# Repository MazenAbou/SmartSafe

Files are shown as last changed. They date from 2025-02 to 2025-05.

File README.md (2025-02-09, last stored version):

# Smart Safe
The Smart Safe is a secure storage system that can be unlocked using a keypad passcode or fingerprint authentication. This prototype, built using Arduino, allows for quick development and testing.

Hardware Components
Microcontroller: Arduino Uno
Input Modules: 4x4 Keypad, Fingerprint Sensor
Output Modules: LCD Display, Buzzer, LED
Lock Mechanism: Servo Motor
Power Supply: 5V Adapter

How It Works
The user enters a passcode on the keypad OR scans a fingerprint for authentication.
If verified, the safe unlocks (servo motor activates).
If authentication fails, the system gives a warning (buzzer & LED).

Next Step:
Transition from Arduino board to a standalone ATmega328P microcontroller.

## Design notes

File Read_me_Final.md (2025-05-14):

Smart Safe Project
Overview:
The smart safe is for anyone with important documents or stuff who wants to keep them away from their roommate, siblings, parents, kids, or even their wives. It’s portable and can fit in a drawer or under the bed. It has security features that trigger an alarm if someone tampers with it. It can be opened using the tag reader or by entering a code using a keypad. Also, an LCD provides a user interface for menu navigation. Options include changing the password, managing RFID tags, and setting the unlock tone.
Key Features and Components:
Microcontroller Chip (ATMega328P): The brain of this project. It has the program code stored in it. It receives/sends signals between other components through the PCB board.
Power Supply: A 3.7V lithium-ion polymer (LiPo) battery combined with a boost module, which steps the voltage up to 5V, which is sufficient to power the microcontroller and peripherals.
Servo Motor: Connected to the lock tongue. Mechanically controls the locking mechanism. It rotates 90 degrees upon receiving signals from the microcontroller to lock or unlock the safe.
Door Sensor: It detects the status of the safe’s door. If the safe is locked and the door is moving, it will send a signal to the microcontroller, and the alarm will be triggered. Also, when the safe door closes, the lock automatically activates, and it prevents the lock from being activated if the door is open.
Card reader (RFID) module: This will give the user the option to open the lock using an authorized RFID card instead of entering a password.
16x2 LCD Display: It will display the lock status and the menu, which will allow the user to choose the option to change the password, or add/remove a tag, and set a tone when the lock opens.
4 x 4 Keypad: This will allow the user to navigate through the menu and enter the password.
Operation Instructions:
First, connect the Smart Safe to a power source using USB-C.
Once powered, the LCD will initialize and prompt the user to enter the default password. Using the keypad, enter the numbers “1234”.
Upon successful entry, a tone will play, and a message will indicate that the safe is unlocked. You will have five seconds to open the safe’s door before it relocks automatically. Open the safe’s door by pulling the handle upward carefully. The door can rotate up to 90 degrees.
 After opening the door, press the “D” key to access the main menu. Navigate through the menu with the buttons “A” to go up, “B” to go down, “C” to select, and “D” to go back.
To change the password, go up to the first option on the menu, then hit “C”. You will be prompted to enter the old password, enter “1234”, then you will be prompted to enter the new password. Enter a four-digit password of your choice, A confirmation message will appear upon success, “Password Changed”.
To add/remove tags, go to the second option on the menu “Add/Remove tags” and hit “C”. You will see two options: “Add tags” and “Remove tags”. Select the first option to add a new tag and hit “C”. You will be prompted to tap the new tag. Grab the tag you want to add and tap it on the safe around one inch below the LCD. A message will appear, “Tag is added.” Hit “D” to go back to the “Add/Remove tags” menu. You can check all registered tags and remove them by selecting the second option, “Remove tags” and hit “C”. A list of all registered tags will be displayed. Navigate to the one you would like to remove and hit the key “C”. You will be prompted to hit the key “C” again if you are sure or you can hit “D” to cancel and go back to the list.
The third option on the main menu is to change the tone that will be played when the lock opens. Select the third option, “Opening tones” then hit “C”. A list of tones will appear, each tone has a name that describes the tone. You can select the tone you like by pushing the key “C”, or you can turn it off by going all the way up to the first option “off” and hitting the button “C”. 
Future Improvements
Possible upgrades include opening the safe via fingerprint. Wi-Fi connectivity for remote monitoring, and a mobile app for access control and notifications.

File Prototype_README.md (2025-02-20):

# Smart Safe
The Smart Safe is a secure storage system that can be unlocked using a keypad passcode. This prototype, built using Arduino, allows for quick development and testing.

Hardware Components
Microcontroller: Arduino Uno
Input Modules: 4x4 Keypad.
Output Modules: LCD Display, Buzzer, LEDs
Lock Mechanism: Servo Motor
Power Supply: 5V / 12V Adapter

How It Works
The user enters a passcode on the keypad.
If verified, the safe unlocks (servo motor activates).
If authentication fails, the system gives a warning (buzzer & LED).

Next Step:
Transition from Arduino board to a standalone ATmega328P microcontroller, adding a card reader, and approach sensor (or similar).

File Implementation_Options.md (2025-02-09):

The Smart Safe system can be implemented using different architectures based on the level of security, complexity, and scalability required. 

Option 1: Microcontroller-Based (Arduino).
Pros:
Simple and cost-effective.
Low power consumption.
Ideal for standalone operation.
Cons:
Limited storage for logging access.
No built-in remote access without additional modules.
Architecture:
Microcontroller 
  -  Arduino as the central processing unit.
  -  Keypad & Fingerprint Sensor as input.
  -  Solenoid Lock/Servo Motor.
  -  LCD Display for feedback.
  -  EEPROM/Flash Memory to store credentials.

Option 2: Raspberry Pi-Based.
Pros:
- More processing power and storage.
- Allows for network-based control (Wi-Fi, Bluetooth, Cloud integration).
Cons:
- Higher power consumption.
- More complex software development.
Architecture:
- Raspberry Pi as the processing unit.
- Touchscreen UI (Optional) instead of a keypad.
- Cloud-based authentication (Optional).

Option 3: Standalone ATmega328P (Without Arduino Board).
  Pros:
- Smaller and cheaper than a full Arduino board.
- More customizable and power-efficient for production use.
- Works well for battery-powered applications.
  Cons:
- Requires external components (crystal oscillator, capacitors, voltage regulator).
- Harder to debug compared to an Arduino board.
  Architecture:
- ATmega328P microcontroller (flashed with Arduino bootloader).
- External 16MHz crystal oscillator with capacitors.
- Manual wiring for inputs (keypad, fingerprint sensor, lock mechanism).
- EEPROM or Flash memory for storing credentials.
- Power regulation circuit (if using external battery).

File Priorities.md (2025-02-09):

High Priority:
1 - Basic Authentication System
    a) Keypad input for passcode entry.
    b) Fingerprint sensor for biometric authentication.
2 - Lock Mechanism
    a) Connect and control solenoid lock/servo motor.
    b) Ensure the lock securely engages/disengages upon authentication.
3 - Power System
    a) Main power supply (adapter or battery).
    b) Implement low-power mode to optimize energy consumption.
4 - Basic Feedback System
    a) Display status messages (successful unlock, incorrect passcode, etc.).
    b) Use buzzer/LEDs for confirmation and alerts.
    
Medium Priority (Security & Usability Enhancements)
1 - Store passcodes and fingerprint data securely in EEPROM/flash memory.
2 - Maintain logs of unlock attempts (successful and failed).
3 - Implement a backup power source for operation during power failure.

Low Priority
1 - Optional Wi-Fi/Bluetooth connectivity to unlock remotely.
2 - Use vibration or magnetic sensors to detect forced entry attempts.
3 - Allow storing multiple fingerprints and passcodes for different users.

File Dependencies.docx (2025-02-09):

# Smart Safe - Dependencies

## 1. Hardware Dependencies

Component | Dependency | Description
Microcontroller (Arduino) | Power Supply | Requires stable power for operation.
Keypad (4x4 Matrix) | Microcontroller | Needs GPIO pins for input detection.
Fingerprint Sensor (R307, GT-511C3) | Microcontroller, Storage | Requires UART/SPI/I2C communication and memory for storing fingerprints.
Lock Mechanism (Solenoid/Servo Motor) | Microcontroller, Power | Needs control signals and sufficient power to operate.
LCD Display | Microcontroller | Requires I2C/SPI communication for visual feedback.
Buzzer/LED Indicator | Microcontroller | Needs GPIO pins to provide user feedback.
Power Supply (Adapter/Battery) | All Components | Supplies energy for the entire system.
Battery Backup (Optional) | Power Supply | Provides power in case of failure.

## 2. Software Dependencies

Feature | Dependency | Description
Keypad Input Handling | Microcontroller Firmware | Requires a code library to read and process inputs.
Fingerprint Authentication | Microcontroller, Sensor Driver | Needs a driver for the fingerprint module and storage for enrolled prints.
Lock Control | Microcontroller, Motor Driver | Requires control logic to activate/deactivate the lock.
User Interface (Display & Buzzer) | Microcontroller Code | Needs code to display messages and provide feedback.
Power Management | Microcontroller, Power Circuit | Requires logic for handling low power mode and switching to backup.
Data Storage (Passcodes & Fingerprints) | EEPROM/Flash Memory | Needs memory allocation and secure storage handling.

## 3. Functional Dependencies

Feature | Depends On | Description
Unlocking the Safe | Keypad/Fingerprint, Microcontroller, Lock Mechanism | Needs user input and control logic to operate the lock.
Security Alerts (Buzzer, Logs) | Microcontroller, Sensors | Requires a trigger system for failed attempts or tamper detection.
Power Backup Activation | Battery, Power Circuit | Needs a switching mechanism when the main power fails.

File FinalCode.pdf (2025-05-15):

#include <Wire.h>

#include <LiquidCrystal_I2C.h>

#include <Keypad.h>

#include <Servo.h>

#include <MFRC522.h>

#define SS_PIN 10

#define RST_PIN 9

MFRC522 mfrc522(SS_PIN, RST_PIN);

LiquidCrystal_I2C lcd(0x27, 16, 2); // Change 0x27 if needed

Servo safeServo;

// Keypad Setup

const byte ROWS = 4;

const byte COLS = 4;

char keys[ROWS][COLS] = {

{'1', '2', '3', 'A'},

{'4', '5', '6', 'B'},

{'7', '8', '9', 'C'},

{'*', '0', '#', 'D'}

};

byte rowPins[ROWS] = {2, 3, 4, 5};

byte colPins[COLS] = {6, 7, 8, A0};

Keypad keypad = Keypad(makeKeymap(keys), rowPins, colPins, ROWS, COLS);

bool isSafeOpen = false;

bool inMenu = false;

bool inTuneMenu = false;

bool inPasswordChange = false;

bool inRFIDManagement = false;

bool inRFIDRemoval = false;

int menuOption = 0;

const int menuLength = 3;

int menuStart = 0;

int selectedTune = 0; // 0 = Mario Tune, 1 = Fur Elise, 2 = Off

const int buzzerPin = A1;

const int buttonPin = A3; // Button connected to pin A3

String currentPassword = "1234";

String newPassword = "";

const int maxRFIDTags = 10;

byte validRFIDs[maxRFIDTags][4];

int numRFIDTags = 0;

unsigned long lastActivityTime = 0;

const unsigned long inactivityInterval = 10000; // 10 seconds

unsigned long unlockTime = 0; // Time when the safe was unlocked

int wrongPasswordCount = 0; // Count wrong password attempts

void setup() {

Serial.begin(9600);

SPI.begin();

mfrc522.PCD_Init();

Serial.println("RFID Reader Initialized");

lcd.init();

lcd.backlight();

lcd.clear();

Serial.println("LCD Initialized");

safeServo.attach(A2); // Connect the servo motor to pin A2

pinMode(buzzerPin, OUTPUT);

pinMode(buttonPin, INPUT_PULLUP); // Set button pin as input with internal pull-up resistor

lockSafe();

Serial.println("System Setup Complete");

}

void loop() {

char key = keypad.getKey();

if (key) {

lastActivityTime = millis();

lcd.backlight(); // Turn on the backlight on any activity

Serial.print("Key Pressed: ");

Serial.println(key);

if (!isSafeOpen) {

handleSafeUnlock(key);

} else {

if (inTuneMenu) {

handleTuneSelection(key);

} else if (inPasswordChange) {

handleChangePassword(key);

} else if (inRFIDManagement) {

handleRFIDManagement(key);

} else if (inRFIDRemoval) {

handleRFIDRemoval(key);

} else if (inMenu) {

handleMenuSelection(key);

} else {

handleMenuNavigation(key);

}

}

}

// Check for RFID tag

if (!isSafeOpen && mfrc522.PICC_IsNewCardPresent() && mfrc522.PICC_ReadCardSerial()) {

lastActivityTime = millis();

lcd.backlight(); // Turn on the backlight on any activity

Serial.println("RFID Tag Detected");

if (isValidRFID()) {

unlockSafe();

} else {

lcd.clear();

lcd.setCursor(0, 0);

lcd.print("Invalid RFID Tag");

delay(1500);

showWelcomeScreen();

}

mfrc522.PICC_HaltA();

}

// Check if the button is pressed and the safe is open

if (isSafeOpen && digitalRead(buttonPin) == LOW) {

if (millis() - unlockTime > inactivityInterval) {

delay(500);

lockSafe();

}

}

// Check if the safe is locked and the button is unpushed

if (!isSafeOpen && digitalRead(buttonPin) == HIGH) {

unsigned long sirenStartTime = millis();

while (!isSafeOpen && digitalRead(buttonPin) == HIGH && millis() - sirenStartTime < 5000) {

playPoliceSiren();

}

noTone(buzzerPin); // Stop the buzzer after 5 seconds

}

// Turn off the backlight after inactivity

if (millis() - lastActivityTime > inactivityInterval) {

lcd.noBacklight();

}

}

void showWelcomeScreen() {

lcd.clear();

lcd.setCursor(0, 0);

lcd.print("Enter Password");

lcd.setCursor(0, 1);

lcd.print("Or Scan a Tag");

}

void lockSafe() {

Serial.println("Locking Safe");

safeServo.write(0);

isSafeOpen = false;

inMenu = false;

lcd.clear();

lcd.setCursor(0, 0);

lcd.print("Safe Locked");

delay(2000);

showWelcomeScreen();

Serial.println("Safe Locked");

}

void unlockSafe() {

Serial.println("Unlocking Safe");

safeServo.write(90);

isSafeOpen = true;

unlockTime = millis(); // Record the time when the safe is unlocked

lcd.clear();

lcd.setCursor(0, 0);

lcd.print("Safe Opened");

playTune();

delay(1000);

showPostUnlockScreen();

Serial.println("Safe Opened");

}

void showPostUnlockScreen() {

lcd.clear();

lcd.setCursor(0, 0);

lcd.print("Press '1'");

lcd.setCursor(0, 1);

lcd.print("for Menu");

}

void handleSafeUnlock(char key) {

static String enteredCode = "";

static bool isEnteringPassword = false;

if (key == '#') {

enteredCode = "";

isEnteringPassword = false;

showWelcomeScreen();

} else if (isDigit(key)) { // Add this condition to check if the key is a digit

if (!isEnteringPassword) {

lcd.clear();

lcd.setCursor(0, 0);

lcd.print("Entering Password...");

isEnteringPassword = true;

}

enteredCode += key;

lcd.setCursor(0, 1);

for (int i = 0; i < enteredCode.length(); i++) {

lcd.print('*');

}

if (enteredCode.length() == currentPassword.length()) {

if (enteredCode == currentPassword) {

unlockSafe();

wrongPasswordCount = 0; // Reset the wrong password count

} else {

wrongPasswordCount++;

lcd.clear();

lcd.setCursor(0, 0);

lcd.print("Wrong Code!");

Serial.println("Wrong Code Entered");

delay(1500);

if (wrongPasswordCount >= 3) {

unsigned long sirenStartTime = millis();

while (millis() - sirenStartTime < 5000) {

playPoliceSiren(); // Play the siren if wrong password entered 3 times

}

noTone(buzzerPin); // Stop the buzzer after 5 seconds

wrongPasswordCount = 0; // Reset the wrong password count after playing the siren

}

showWelcomeScreen();

}

enteredCode = "";

isEnteringPassword = false;

}

}

}

void handleMenuNavigation(char key) {

if (key == '1') {

inMenu = true;

menuOption = 0;

menuStart = 0;

showMenu();

}

}

void showMenu() {

lcd.clear();

updateMenuDisplay();

Serial.println("Menu Displayed");

}

void updateMenuDisplay() {

lcd.clear();

for (int i = 0; i < 2; i++) {

int menuIndex = menuStart + i;

if (menuIndex < menuLength) {

lcd.setCursor(0, i); // Start menu options one more space to the right

lcd.print(menuIndex == menuOption ? "> " : " ");

switch (menuIndex) {

case 0: lcd.print("Change Password"); break;

case 1: lcd.print("Manage Tags"); break;

case 2: lcd.print("Opening Tune"); break;

}

}

}

Serial.print("Menu Option: ");

Serial.println(menuOption);

}

void handleMenuSelection(char key) {

if (key == 'A' && menuOption > 0) {

menuOption--;

if (menuOption < menuStart) menuStart--;

} else if (key == 'B' && menuOption < menuLength - 1) {

menuOption++;

if (menuOption >= menuStart + 2) menuStart++;

} else if (key == '6') {

if (menuOption == 0) {

showPasswordChangeScreen(); // Call this function when the "Change Password" option is selected

} else if (menuOption == 1) {

showRFIDManagementMenu();

} else if (menuOption == 2) {

showTuneMenu();

}

} else if (key == '1') {

inMenu = false;

showPostUnlockScreen();

return;

}

updateMenuDisplay();

}

void showTuneMenu() {

inTuneMenu = true;

menuOption = 0;

lcd.clear();

updateTuneMenu();

Serial.println("Tune Menu Displayed");

}

void updateTuneMenu() {

lcd.clear();

for (int i = 0; i < 2; i++) {

int menuIndex = menuStart + i;

if (menuIndex < 3) {

lcd.setCursor(0, i); // Start menu options one more space to the right

lcd.print(menuIndex == menuOption ? "> " : " ");

switch (menuIndex) {

case 0: lcd.print("Mario Tune"); break;

case 1: lcd.print("Fur Elise"); break;

case 2: lcd.print("Off"); break;

}

}

}

Serial.print("Tune Menu Option: ");

Serial.println(menuOption);

}

void handleTuneSelection(char key) {

if (key == 'A' && menuOption > 0) {

menuOption--;

if (menuOption < menuStart) menuStart--;

} else if (key == 'B' && menuOption < 2) {

menuOption++;

if (menuOption >= menuStart + 2) menuStart++;

} else if (key == '6') {

selectedTune = menuOption;

lcd.clear();

lcd.setCursor(0, 0);

lcd.print("Tune Selected!");

Serial.print("Tune Selected: ");

Serial.println(selectedTune == 0 ? "Mario Tune" : selectedTune == 1 ? "Fur Elise" : "Off");

delay(1000);

inTuneMenu = false;

showMenu();

} else if (key == '1') {

inTuneMenu = false;

showMenu();

}

updateTuneMenu();

}

void showPasswordChangeScreen() {

inPasswordChange = true;

lcd.clear();

lcd.setCursor(0, 0);

lcd.print("Enter Old Password:");

}

void handleChangePassword(char key) {

static String enteredOldPassword = "";

static String enteredNewPassword = "";

static bool enteringOldPassword = true;

static bool isEnteringPassword = false;

if (key == '1') {

enteredOldPassword = "";

enteredNewPassword = "";

enteringOldPassword = true;

isEnteringPassword = false;

inPasswordChange = false;

showMenu();

} else if (key == '#') {

enteredOldPassword = "";

enteredNewPassword = "";

enteringOldPassword = true;

isEnteringPassword = false;

showPasswordChangeScreen();

} else if (isDigit(key)) { // Add this condition to check if the key is a digit

if (!isEnteringPassword) {

lcd.clear();

lcd.setCursor(0, 0);

if (enteringOldPassword) {

lcd.print("Old Password:");

} else {

lcd.print("New Password:");

}

isEnteringPassword = true;

}

if (enteringOldPassword) {

enteredOldPassword += key;

lcd.setCursor(0, 1);

for (int i = 0; i < enteredOldPassword.length(); i++) {

lcd.print('*');

}

if (enteredOldPassword.length() == currentPassword.length()) {

if (enteredOldPassword == currentPassword) {

lcd.clear();

lcd.setCursor(0, 0);

lcd.print("Enter New Pass:");

enteredOldPassword = "";

enteringOldPassword = false;

isEnteringPassword = false;

} else {

lcd.clear();

lcd.setCursor(0, 0);

lcd.print("Wrong Pass!");

delay(1500);

showPasswordChangeScreen();

enteredOldPassword = "";

isEnteringPassword = false;

}

}

} else {

enteredNewPassword += key;

lcd.setCursor(0, 1);

for (int i = 0; i < enteredNewPassword.length(); i++) {

lcd.print('*');

}

if (enteredNewPassword.length() == currentPassword.length()) {

newPassword = enteredNewPassword;

currentPassword = newPassword;

lcd.clear();

lcd.setCursor(0, 0);

lcd.print("Pass Changed!");

Serial.println("Password Changed Successfully");

delay(1500);

inPasswordChange = false;

showMenu();

}

}

}

}

void showRFIDManagementMenu() {

inRFIDManagement = true;

menuOption = 0;

lcd.clear();

updateRFIDManagementMenu();

Serial.println("RFID Management Menu Displayed");

}

void updateRFIDManagementMenu() {

lcd.clear();

lcd.setCursor(0, 0); // Start menu options one more space to the right

lcd.print(menuOption == 0 ? "> Add Tags" : " Add Tags");

lcd.setCursor(0, 1);

lcd.print(menuOption == 1 ? "> Remove Tags" : " Remove Tags");

Serial.print("Tags Management Option: ");

Serial.println(menuOption);

}

void handleRFIDManagement(char key) {

if (key == 'A' && menuOption > 0) {

menuOption--;

} else if (key == 'B' && menuOption < 1) {

menuOption++;

} else if (key == '6') {

if (menuOption == 0) {

addRFIDTag();

} else if (menuOption == 1) {

showRFIDRemovalScreen();

}

} else if (key == '1') {

inRFIDManagement = false;

showMenu();

}

updateRFIDManagementMenu();

}

void addRFIDTag() {

lcd.clear();

lcd.setCursor(0, 0);

lcd.print("Scan New Tag:");

Serial.println("Waiting for new RFID tag...");

while (!mfrc522.PICC_IsNewCardPresent() || !mfrc522.PICC_ReadCardSerial()) {

delay(100);

}

if (numRFIDTags < maxRFIDTags) {

for (int i = 0; i < 4; i++) {

validRFIDs[numRFIDTags][i] = mfrc522.uid.uidByte[i];

}

numRFIDTags++;

lcd.clear();

lcd.setCursor(0, 0);

lcd.print("Tag Added!");

Serial.println("New tag added");

} else {

lcd.clear();

lcd.setCursor(0, 0);

lcd.print("Max Tags Reached");

Serial.println("Max RFID tags reached");

}

delay(1500);

showRFIDManagementMenu();

}

void showRFIDRemovalScreen() {

inRFIDRemoval = true;

menuOption = 0;

lcd.clear();

updateRFIDRemovalScreen();

Serial.println("RFID Removal Screen Displayed");

}

void updateRFIDRemovalScreen() {

lcd.clear();

if (numRFIDTags == 0) {

lcd.setCursor(0, 0);

lcd.print("No Tags Stored");

Serial.println("No Tags Stored");

delay(1500);

showRFIDManagementMenu();

return;

}

lcd.setCursor(0, 0); // Start menu options one more space to the right

lcd.print(menuOption == 0 ? "> " : " ");

for (int j = 0; j < 4; j++) {

lcd.print(validRFIDs[menuOption][j], HEX);

if (j < 3) lcd.print(":");

}

Serial.print("RFID Removal Option: ");

Serial.println(menuOption);

}

void handleRFIDRemoval(char key) {

if (key == 'A' && menuOption > 0) {

menuOption--;

} else if (key == 'B' && menuOption < numRFIDTags - 1) {

menuOption++;

} else if (key == '6') {

removeRFIDTag(menuOption);

} else if (key == '1') {

inRFIDRemoval = false;

showRFIDManagementMenu();

}

updateRFIDRemovalScreen();

}

void removeRFIDTag(int index) {

for (int i = index; i < numRFIDTags - 1; i++) {

for (int j = 0; j < 4; j++) {

validRFIDs[i][j] = validRFIDs[i + 1][j];

}

}

numRFIDTags--;

lcd.clear();

lcd.setCursor(0, 0);

lcd.print("Tag Removed!");

Serial.println("RFID tag removed");

delay(1500);

if (numRFIDTags == 0) {

inRFIDRemoval = false;

showRFIDManagementMenu();

} else {

updateRFIDRemovalScreen();

}

}

void playTune() {

if (selectedTune == 0) {

playMarioTune();

} else if (selectedTune == 1) {

playFurElise();

}

}

void playMarioTune() {

int melody[] = {262, 262, 392, 392, 440, 440, 392};

int duration[] = {300, 300, 300, 300, 300, 300, 600};

for (int i = 0; i < 7; i++) {

tone(buzzerPin, melody[i], duration[i]);

delay(duration[i] + 50);

}

Serial.println("Played Mario Tune");

}

void playFurElise() {

int melody[] = {330, 311, 330, 311, 330, 247, 311, 262};

int duration[] = {300, 300, 300, 300, 300, 300, 300, 600};

for (int i = 0; i < 8; i++) {

tone(buzzerPin, melody[i], duration[i]);

delay(duration[i] + 50);

}

Serial.println("Played Fur Elise");

}

void playPoliceSiren() {

for (int i = 440; i < 1000; i += 10) { // Increase pitch (woo)

tone(buzzerPin, i);

delay(20);

}

for (int i = 1000; i > 440; i -= 10) { // Decrease pitch (woo)

tone(buzzerPin, i);

delay(20);

}

}

bool isValidRFID() {

for (int i = 0; i < numRFIDTags; i++) {

bool match = true;

for (int j = 0; j < 4; j++) {

if (validRFIDs[i][j] != mfrc522.uid.uidByte[j]) {

match = false;

break;

}

}

if (match) {

return true;

}

}

return false;

}

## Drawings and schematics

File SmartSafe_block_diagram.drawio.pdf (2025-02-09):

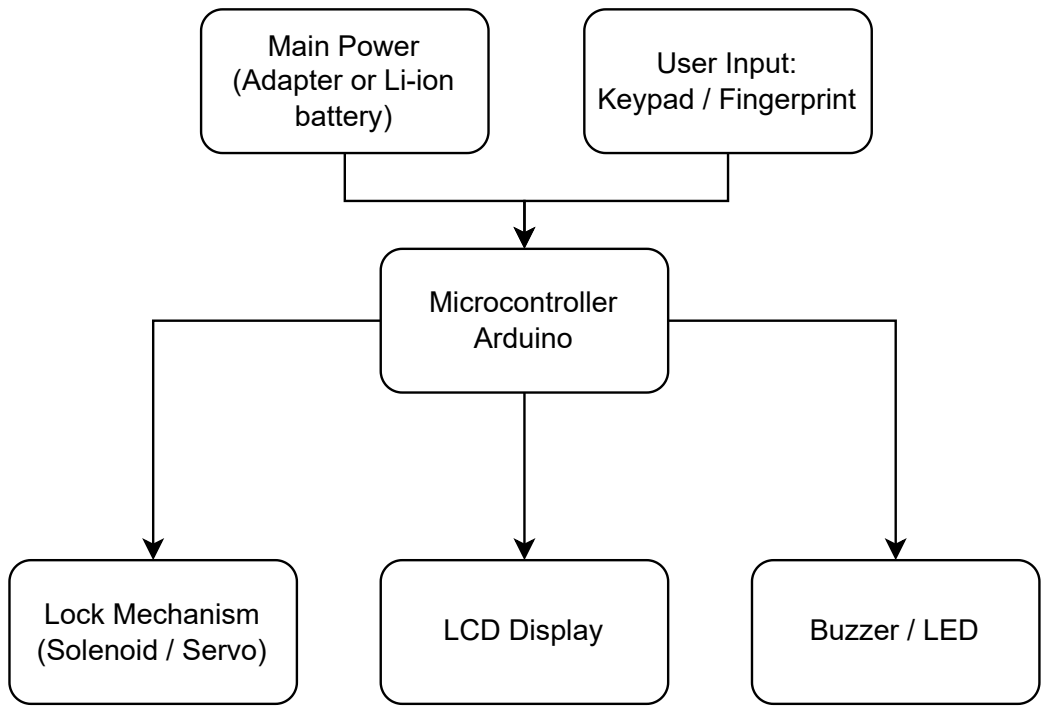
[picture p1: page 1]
Microcontroller Arduino; LCD Display; Buzzer / LED Lock Mechanism; (Solenoid / Servo); User Input: Keypad / Fingerprint

Main Power
(Adapter or Li-ion
battery)

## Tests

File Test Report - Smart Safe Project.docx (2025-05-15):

### Test Report - Smart Safe Project

## 1. Functional Tests

### Test 1: Keypad Entry Test

- Objective: Verify that the keypad allows entry with the correct PIN and denies access for incorrect PINs.
- Test Steps:
  1. Enter the correct PIN.
  2. Observe whether the servo motor unlocks
  3. Enter an incorrect PIN
  4. Observe if the system remains locked.
- Expected Result: Correct PIN unlocks the safe; incorrect PIN denies access.
- Actual Result: Pass

### Test 2: Servo Lock Mechanism

- Objective: Confirm that the servo motor properly locks and unlocks the safe.
- Test Steps:
  1. Send an unlock command via the keypad.
  2. Observe if the servo motor rotates to unlock.
  3. Send a lock command.
  4. Observe if the servo motor rotates to lock.
- Expected Result: Servo motor locks/unlocks the safe as expected.
- Actual Result: Pass

### Test 3: LCD display

- Objective: Confirm that the display is clear and readable.
- Test Steps:
  5. Wired the display and connected it to the Arduino using I2C.
  6. Ran a test code from the Arduino to the display and checked if the display displayed the code.
  7. Rotate the I2C potentiometer clockwise or counterclockwise to find the optimal contrast level for the display.
- Expected Result: pass
- Actual Result: Pass

### Test 4: RFID card reader

- Objective: Confirm that the RFID can read tags..
- Test Steps:
  8. Wired the RFID and connected it to the Arduino
  9. Assign an RFID tag and program the Arduino to turn on the LED if it reads the correct tag if otherwise, no.
- Expected Result: pass
- Actual Result: Pass

## - Performance Tests

### Test 5: Response Time Test

- Objective: Measure how long it takes for the safe to unlock after authentication.
- Test Steps:
  1. Authenticate using a correct PIN.
  2. Record the time taken for the safe to unlock.
- Expected Result: The unlock process is completed within 1 second.
- Actual Result: Less than a second

### Test 6: Power Test

- Objective: Check if the safe’s battery can charge when the power boost is connected to a power source.
- Test Steps:
  1. Connecting the power boost to a power source using USB-C.
  2. Check if the power boost is charging the battery by the LED indicators.
  3. Check how long the battery will last before it needs to be recharged.
- Expected Result: The Power boost can charge the battery, and it lasts for a week.
- Actual Result:
  4. The battery takes 60 minutes to fully charge.
  5. It takes 10 days to discharge with normal daily use.

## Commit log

2025-02-09 Modules - Prototype (Using Arduino)
2025-02-20 Modules - Prototype (Using Arduino)
    We will not be able to use the fingerprint sensor due to its price and its programming difficulty.
2025-02-20 Update and rename README.md to Prototype_README.md
2025-03-11 Safe Lock Kicad (3/11/2025)
    [SmartSafe.kicad_pcb, SmartSafe.kicad_sch]
